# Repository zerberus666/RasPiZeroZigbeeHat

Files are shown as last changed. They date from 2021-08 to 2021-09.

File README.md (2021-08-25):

# Raspberry Pi Zero ~~pHat~~ uHat template

This a KiCad 5.0.0 template for a [Raspberry Pi Zero](https://www.raspberrypi.org/products/raspberry-pi-zero/) or [Raspberry Pi Zero W](https://www.raspberrypi.org/products/raspberry-pi-zero-w/) sized uHat. It is based on the [Raspberry Pi B+ Hat template](https://github.com/xesscorp/RPi_Hat_Template) from Xess Corp. They did all the hard work here.

Raspberry Pi Foundation has finally named these Raspberry Pi Zero sized hats which some called pHats. The new name is **Micro-Hat** or **uHat**. They also released a mechanical specification for them [here](https://github.com/raspberrypi/hats/blob/master/uhat-board-mechanical.pdf). Luckily these specifications exactly match the template. Note the new POE keepout area is not in this template. You will have to keep track of it yourself.

Both a thru-hole and a surface mount connector are provided, along with a different PCB edge for each. Just keep the PCB edge and connector type that you're using for your design and delete the others. The surface mount header is on the bottom of the board. Keep in mind if you flip it to the top side even/odd pins will be swapped unless you also switch the foot print to "Samtec_HLE-120-02-xxx-DV-BE-A_2x20_RPi_Top".

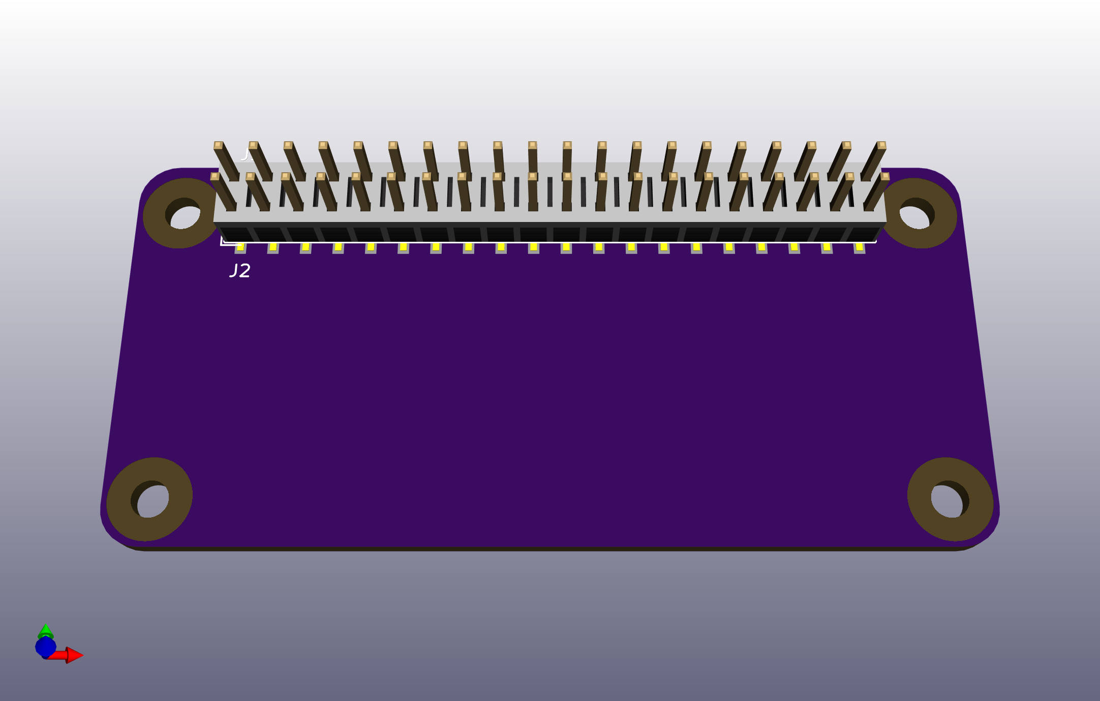
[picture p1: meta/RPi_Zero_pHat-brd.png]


## Using the Template

Follow the instructions listed in the original [Raspberry Pi B+ Hat template](https://github.com/xesscorp/RPi_Hat_Template) from XESS Corp.

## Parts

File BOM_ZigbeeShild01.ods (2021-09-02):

Reference | Quantity | Value | Footprint | Datasheet | примечания
C2 | 1 | 100uF_50V | Capacitor_SMD:CP_Elec_10x10.5 | ~
C3 | 1 | 220uF_35V | Capacitor_SMD:CP_Elec_8x10.5 | ~
C1 C4 | 2 | 100p | Capacitor_SMD:C_0805_2012Metric | ~
C5 | 1 | 22u | Capacitor_SMD:CP_Elec_5x5.4 | ~
C6 | 1 | 0.1u | Capacitor_SMD:C_0805_2012Metric | ~
D1 D2 D5 | 3 | LED | LED_SMD:LED_0603_1608Metric | ~
D4 | 1 | B340 | Diode_SMD:D_SMC | http://www.jameco.com/Jameco/Products/ProdDS/1538777.pdf
J1 | 1 | Conn_01x06_Male | Connector_PinHeader_2.54mm:PinHeader_1x06_P2.54mm_Vertical | ~
J2 | 1 | RPi_GPIO | Connector_PinSocket_2.54mm:PinSocket_2x20_P2.54mm_Vertical |  | На Али
J3 | 1 | Power | Connector_JST:JST_EH_B2B-EH-A_1x02_P2.50mm_Vertical | ~
L1 | 1 | 68uH | Inductor_SMD:L_Bourns_SRR1210A | ~
R1 R2 R4 | 3 | 1k | Resistor_SMD:R_0805_2012Metric | ~
R3 | 1 | 10k | Resistor_SMD:R_0805_2012Metric | ~
SW1 | 1 | BSL | Button_Switch_SMD:SW_SPST_B3U-1000P | ~
SW2 | 1 | RST | Button_Switch_SMD:SW_SPST_B3U-1000P | ~
U1 | 1 | LM2596S-5 | Package_TO_SOT_SMD:TO-263-5_TabPin3 | http://www.ti.com/lit/ds/symlink/lm2596.pdf
U2 | 1 | AMS1117-3.3 | Package_TO_SOT_SMD:SOT-223-3_TabPin2 | http://www.advanced-monolithic.com/pdf/ds1117.pdf
U3 | 1 | RF-BM-2652P2 | Zigbee:RF-BM-2652 |  | На Али

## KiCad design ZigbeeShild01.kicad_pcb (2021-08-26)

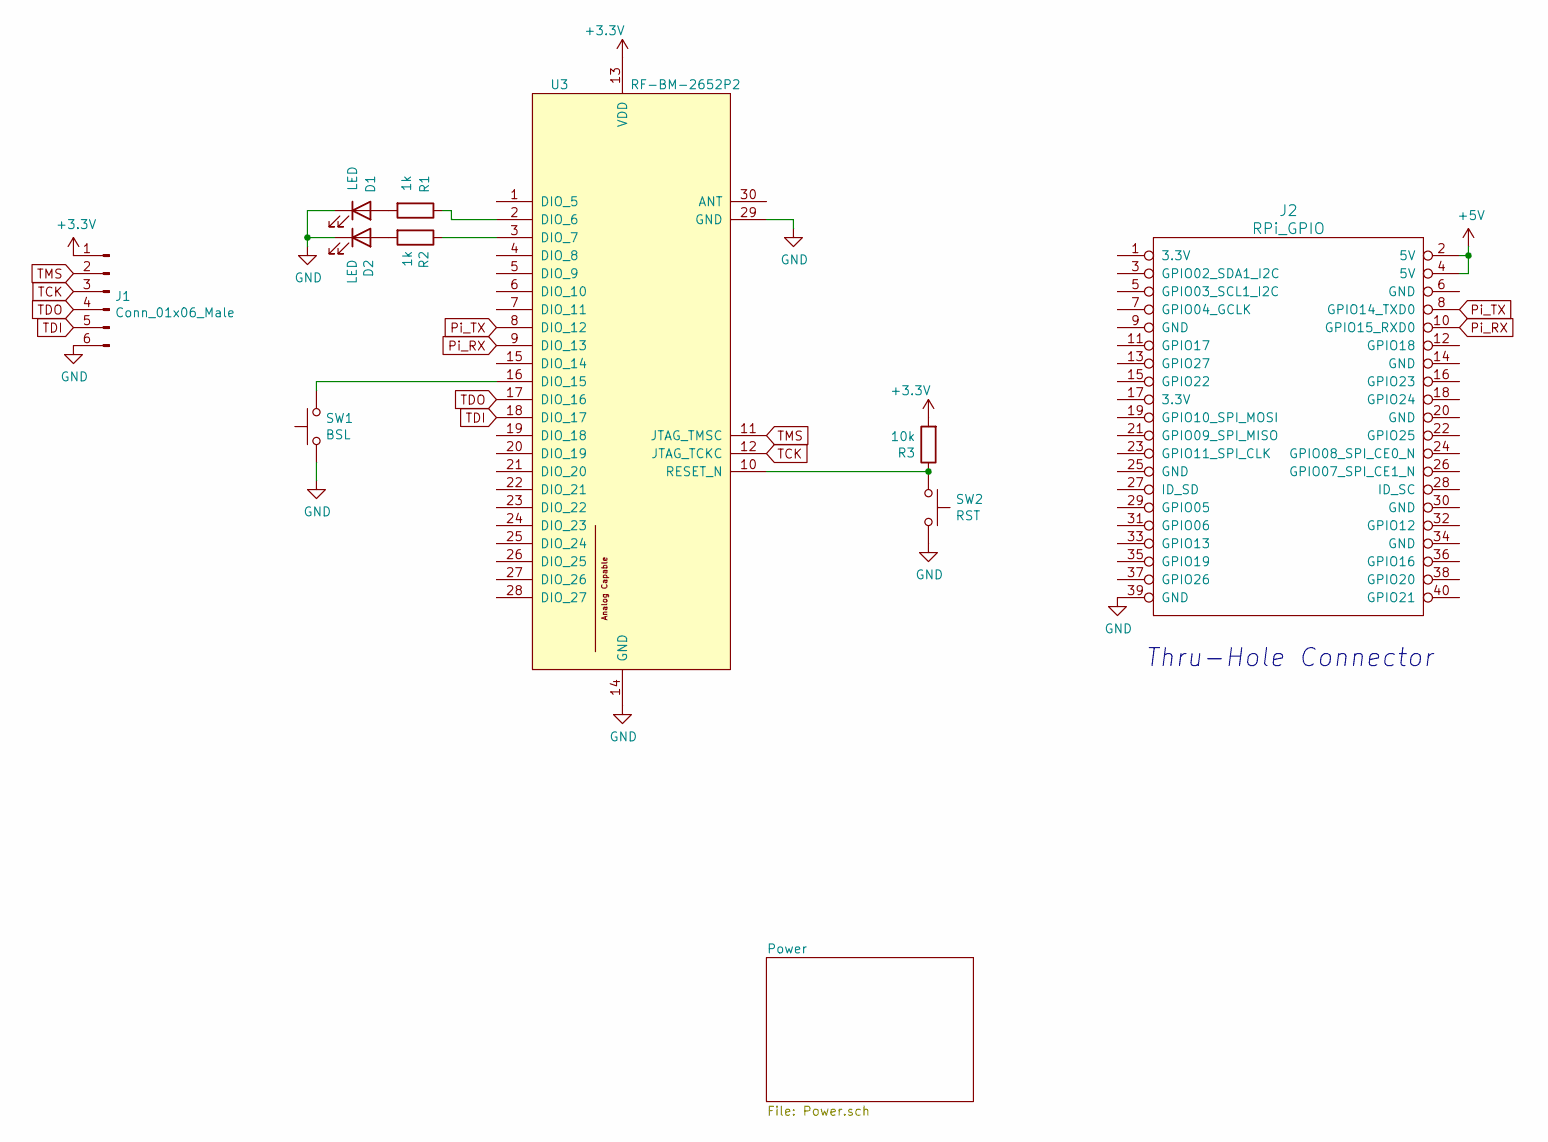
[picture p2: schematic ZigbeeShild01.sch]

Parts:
D1, D2: LED; LED_0603_1608Metric
J1: Conn_01x06_Male; PinHeader_1x06_P2.54mm_Vertical
J2: RPi_GPIO; PinSocket_2x20_P2.54mm_Vertical
R1, R2: 1k; R_0805_2012Metric
R3: 10k; R_0805_2012Metric
SW1: BSL; SW_SPST_B3U-1000P
SW2: RST; SW_SPST_B3U-1000P
U3: RF-BM-2652P2; RF-BM-2652

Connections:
+3V3: J1.1, R3.2, U3.13 (VDD); also elsewhere on the board
+5V: J2.2 (5V), J2.4 (5V); also elsewhere on the board
GND: D1.1 (K), D2.1 (K), J1.6, J2.39 (GND), SW1.1, SW2.2, U3.14 (GND), U3.29 (GND); also elsewhere on the board
unnamed: D1.2 (A), R1.2
unnamed: D2.2 (A), R2.2
unnamed: R1.1, U3.2 (DIO_6)
unnamed: R2.1, U3.3 (DIO_7)
unnamed: R3.1, SW2.1, U3.10 (RESET_N)
unnamed: SW1.2, U3.16 (DIO_15)
Pi_RX: J2.10 (GPIO15_RXD0), U3.9 (DIO_13)
Pi_TX: J2.8 (GPIO14_TXD0), U3.8 (DIO_12)
TCK: J1.3, U3.12 (JTAG_TCKC)
TDI: J1.5, U3.18 (DIO_17)
TDO: J1.4, U3.17 (DIO_16)
TMS: J1.2, U3.11 (JTAG_TMSC)

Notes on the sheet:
Thru-Hole Connector

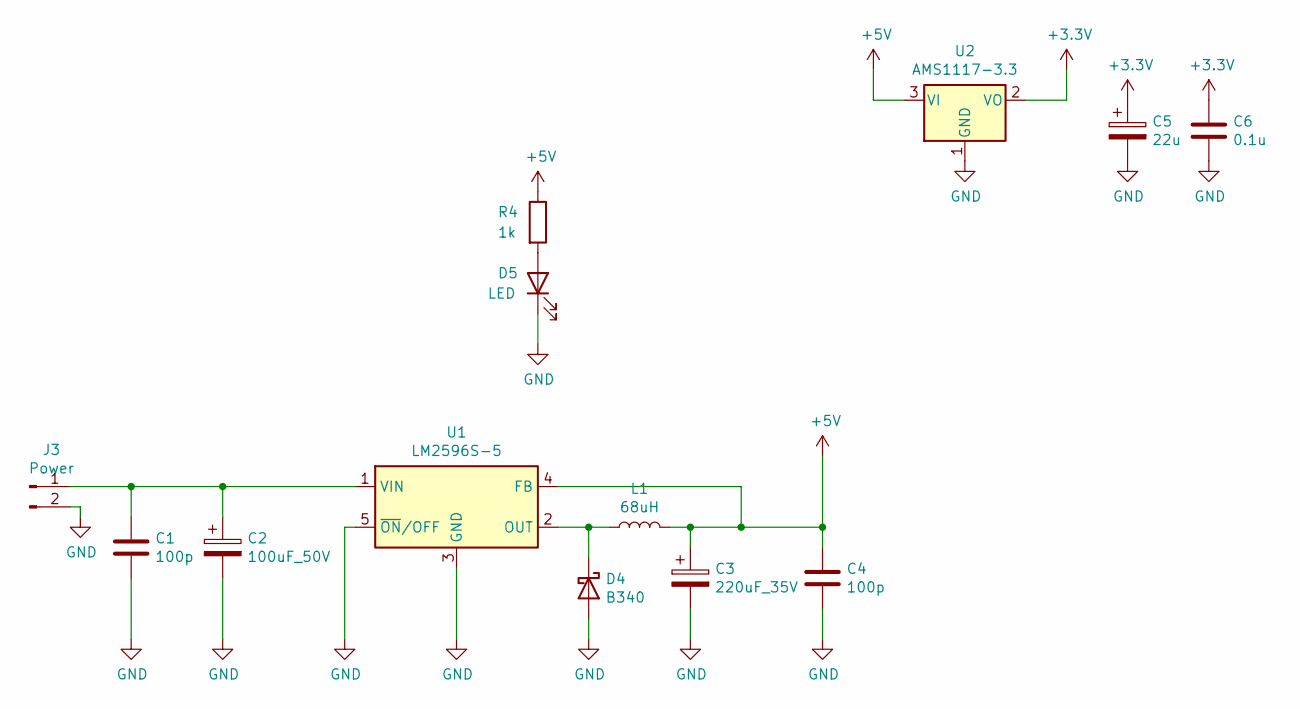
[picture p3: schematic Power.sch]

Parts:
C1, C4: 100p; C_0805_2012Metric
C2: 100uF_50V; CP_Elec_10x10.5
C3: 220uF_35V; CP_Elec_8x10.5
C5: 22u; CP_Elec_5x5.4
C6: 0.1u; C_0805_2012Metric
D4: B340; D_SMC
D5: LED; LED_0603_1608Metric
J3: Power; JST_EH_B2B-EH-A_1x02_P2.50mm_Vertical
L1: 68uH; L_Bourns_SRR1210A
R4: 1k; R_0805_2012Metric
U1: LM2596S-5; TO-263-5_TabPin3
U2: AMS1117-3.3; SOT-223-3_TabPin2

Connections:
+3V3: C5.1, C6.1, U2.2 (VO); also elsewhere on the board
+5V: C3.1, C4.1, L1.2, R4.1, U1.4 (FB), U2.3 (VI); also elsewhere on the board
GND: C1.2, C2.2, C3.2, C4.2, C5.2, C6.2, D4.2 (A), D5.1 (K), J3.2, U1.3 (GND), U1.5 (~ON~/OFF), U2.1 (GND); also elsewhere on the board
unnamed: C1.1, C2.1, J3.1, U1.1 (VIN)
unnamed: D4.1 (K), L1.1, U1.2 (OUT)
unnamed: D5.2 (A), R4.2

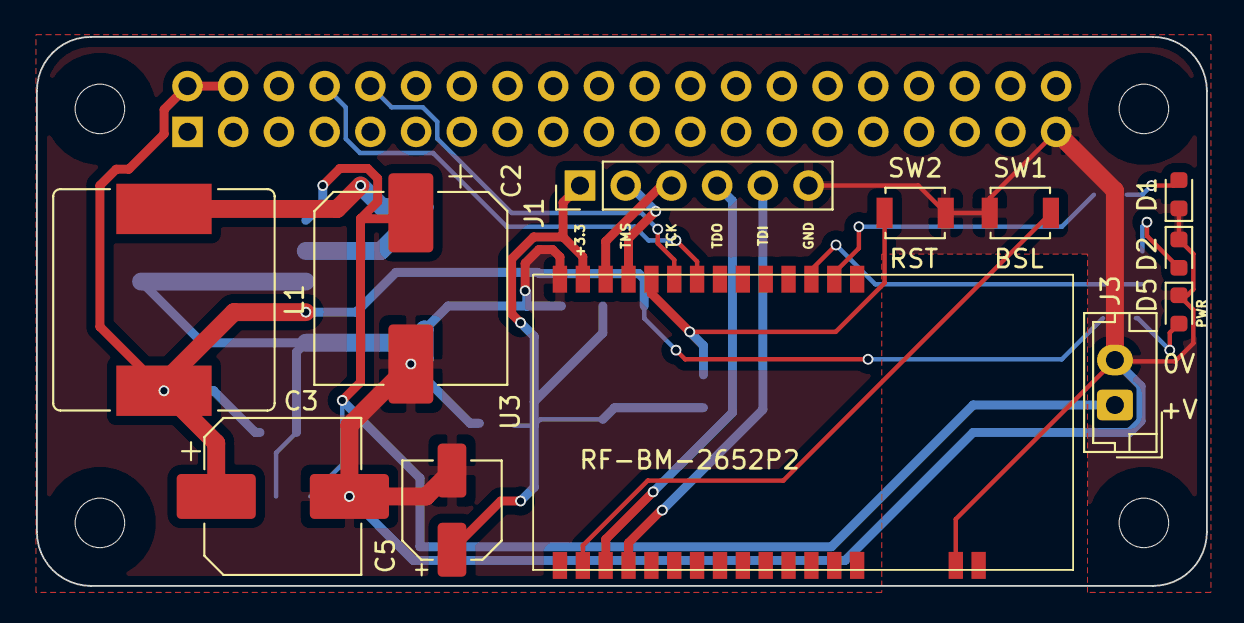
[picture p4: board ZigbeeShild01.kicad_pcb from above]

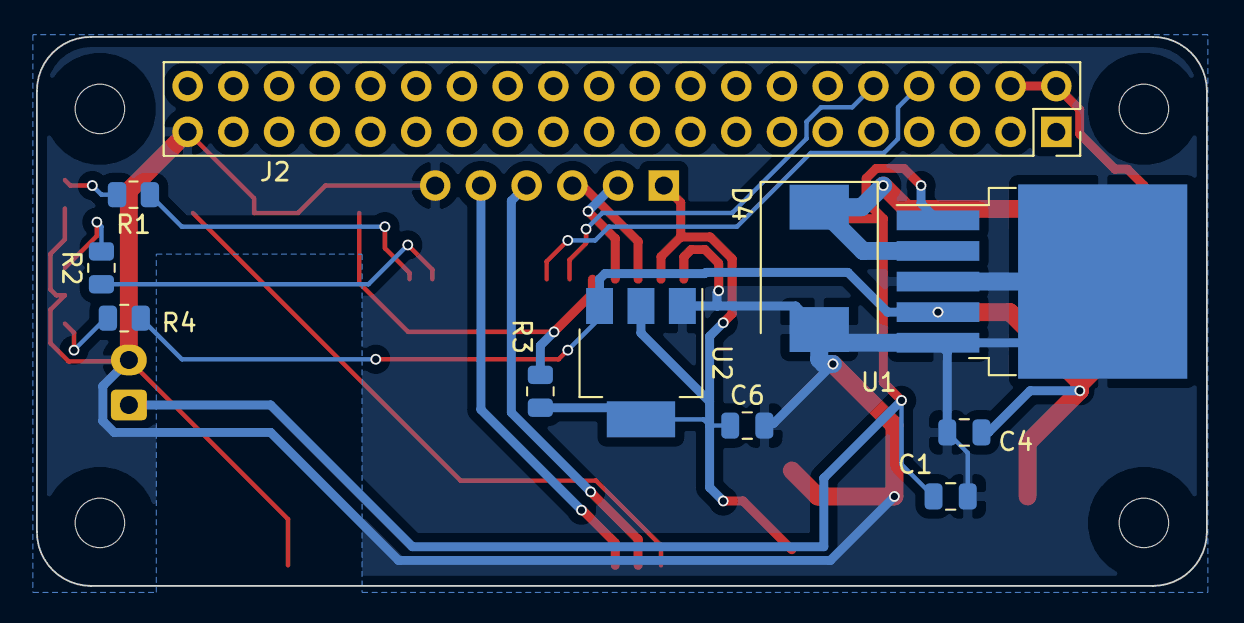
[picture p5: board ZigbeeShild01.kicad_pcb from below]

Board: 2 copper layers, 65.0 x 30.5 mm, 23 parts (11 on the bottom side), 18 nets.

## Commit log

2021-08-25 Gerber Files for production added
    [ZigbeeShild01-B_Cu.gbr, ZigbeeShild01-B_Mask.gbr, ZigbeeShild01-B_SilkS.gbr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]
2021-08-26 some small changes in PCB
    [ZigbeeShild01-B_Cu.gbr, ZigbeeShild01-B_Mask.gbr, ZigbeeShild01-B_SilkS.gbr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]
2021-09-02 BOM and Gerber files generated
    [BOM_ZigbeeShild01.ods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]
2021-11-02 some changes
    [BOM_ZigbeeShild01.ods, Power.sch, ZigbeeShield.kicad_pcb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]
